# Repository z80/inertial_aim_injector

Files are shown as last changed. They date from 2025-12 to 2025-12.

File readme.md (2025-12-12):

# A hardware project - Inertial Aiming Override for DualSense Playstation 5 controller.

| Image 1 | Image 2 |
|---|---|
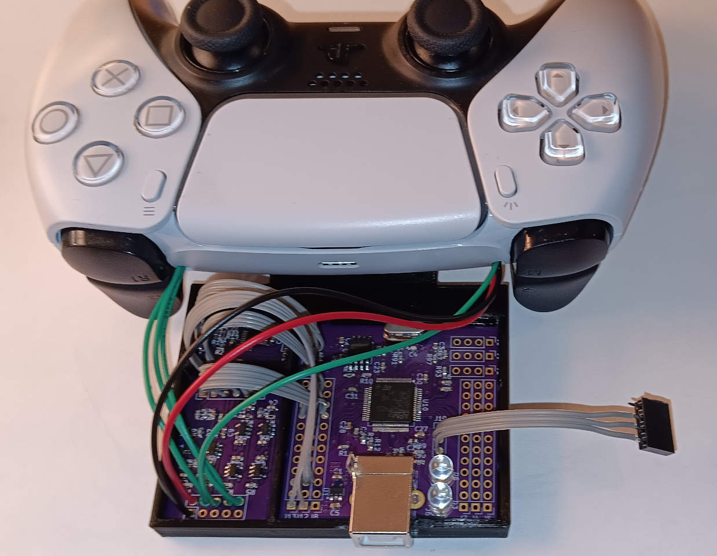
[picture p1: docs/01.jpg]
Image A
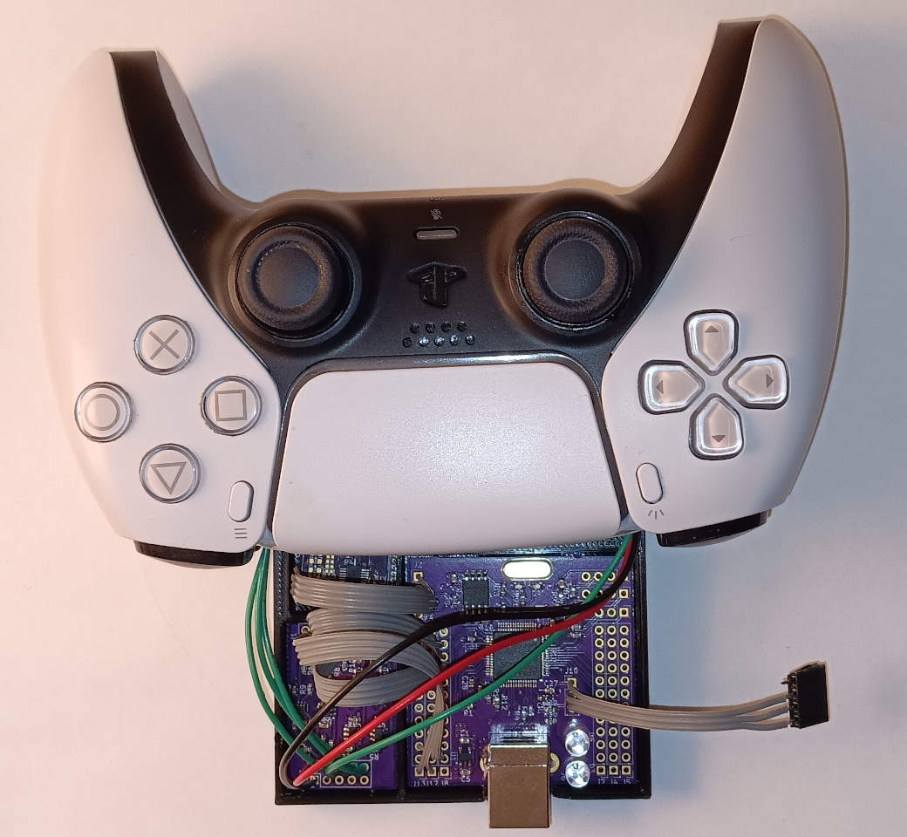
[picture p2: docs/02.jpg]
Image B
|  |  |

Constant overshooting? 
Frustrating undershooting? 
The endless struggle to place the crosshair exactly on target? 
Thumbsticks that refuse to obey your intent? Another great game launches - only for you to discover it does not support inertial aiming? 

Looks familiar?  

**Scenes like these are happening all over the galaxy right now!**

But there is a way forward. 
Forget the fight against clumsy thumbsticks. 
Embrace inertial aiming override.  

Play on par with keyboard and mouse players.  
Achieve precision where there was chaos.  
Experience smooth control where there was frustration.  
Unlock faster reaction times with natural motion input.  

Spread inertial aiming accuracy across every battlefield.  
Use the inertial aiming override device.  
Leave the thumbstick struggle behind.

This repository contains a prototype hardware/firmware project that **overrides the internal thumbstick signals of a PlayStation DualSense controller** using an external inertial sensor (BMI085 IMU).  
The goal: enable **inertial aiming** in games that do not natively support it, by forcing thumbstick input derived from gyroscope/accelerometer data.
There are a few products on the market which filter USB trafic of the controller and inject keyboard and mouse. However, it only can work as soon as it is over USB and not over Bluetooth.
The hardware override ensures that it works no matter what.

---

## Target Games

This override is intended to make aiming more convenient in titles lacking native inertial support:

| Picture | Game | Notes |
|---|---|---|
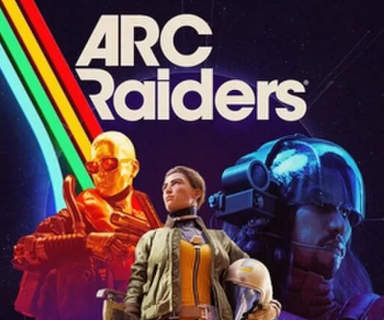
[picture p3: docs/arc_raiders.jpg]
Arc Raiders
|  | Arc Raiders | No native inertial aiming |
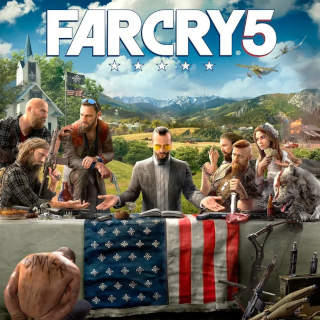
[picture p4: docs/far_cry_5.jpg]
Far Cry 5
|  | Far Cry 5 | No native inertial aiming support neither |
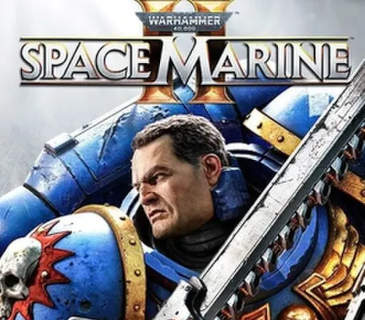
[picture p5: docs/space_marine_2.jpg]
Space Marine 2
|  |Space Marine 2 | No native inertial aiming |
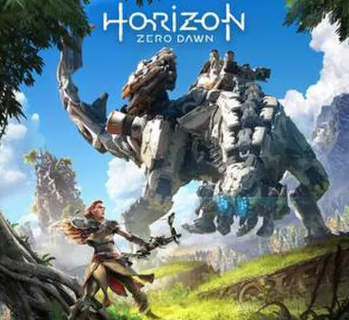
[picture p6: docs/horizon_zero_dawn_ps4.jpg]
Horizon Zero Dawn PS4
|  |Horizon Zero Dawn (PS4) | PS5 version supports inertial aiming but the main character has been made less cute |
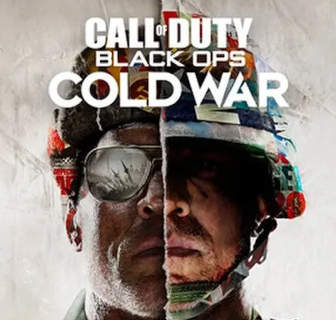
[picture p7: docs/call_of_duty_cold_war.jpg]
call of Duty: Black Ops Cold War
|  |Call of Duty: Black Ops Cold War | No native inertial aiming |
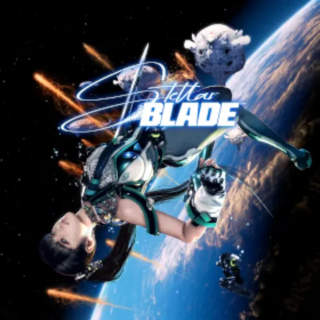
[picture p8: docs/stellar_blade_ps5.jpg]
Stellar Blade PS5
|  |Stellar Blade | No native inertial aiming, needed when shooting targets |

*(More titles may be added as I find out the intertial aiming status)*

---

## 📂 Project Structure

- **`firmware/`**  
  Board configuration for MicroPython firmware supporting the BMI085 IMU.  
  Runs on a custom STM32F405 board with USB‑B and 16 MB SPI flash.

- **`mechanical/`**  
  Blender3D project for the mechanical tray.  
  Designed to attach under the DualSense controller with double‑sided tape.

- **`python/`**  
  Contains `main.py` - the control logic.  
  Current firmware is binary (on/off), but Python makes it easy to experiment with sensitivity curves (e.g., scaling with L2 button depth).

- **`schematics/`**  
  Three PCB designs:
  - `board_bmi085` → breakout for BMI085 IMU  
  - `mp_board` → custom MicroPython‑capable STM32F405RGT6 board with USB‑B and 16MB flash  
  - `override_board` → power management + signal injection  
    - Uses TPS22948 with reverse current blocking  
    - Energizes only when the DualSense thumbsticks are active  
    - Senses L2 button position and drives voltages into the right thumbstick X/Y axes

---

## Deadzone Observations

During testing, the DualSense thumbstick showed **nonsymmetrical deadzones**:

- Neutral voltage - **0.9V**
- Both X and Y axes have insensitive intervals around neutral
- Positive and negative directions differ in width
- Deadzone ranges vary slightly between axes
- Likely **controller-specific**. Different units may have different calibration tables. I only have one to play with.

This means injected signals must account for asymmetric thresholds to achieve smooth inertial aiming.

---

## Disclaimer

This is a **prototype project - not a finished product**.  
- Built for personal experimentation and proof‑of‑concept.  
- If you want to reproduce or extend it, more copies can be made.  
- For compactness and convenience, a **single‑board override design** is recommended (instead of the current 3‑board stack).  

Use at your own risk. This project is not affiliated with Sony or PlayStation.

---

## Future Directions

- Consolidate into a single PCB for easier replication  
- Add configurable sensitivity curves (e.g., proportional to L2 depth)  
- Explore per-controller calibration routines to compensate for asymmetric deadzones  
- Community contributions welcome: firmware tweaks, mechanical refinements, or new game compatibility reports

---

## Project Status

Prototype stage. Contributions, forks, and experiments are encouraged!

---

## Get Involved

This project is still in its prototype stage, but curiosity and experimentation are what keep it alive.  
If the idea of overriding thumbstick signals with inertial aiming sparks your interest, I’d love to hear from you.  

Feel free to open an issue, share your thoughts, or suggest improvements.  
Even a simple "I’d like to try this" helps gauge whether others find value in the concept.  
Your feedback will shape whether this remains a one‑off experiment or grows into something more refined.

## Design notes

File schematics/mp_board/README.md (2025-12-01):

A custom MicroPython-based Stm32 board with integrated Flash memory.

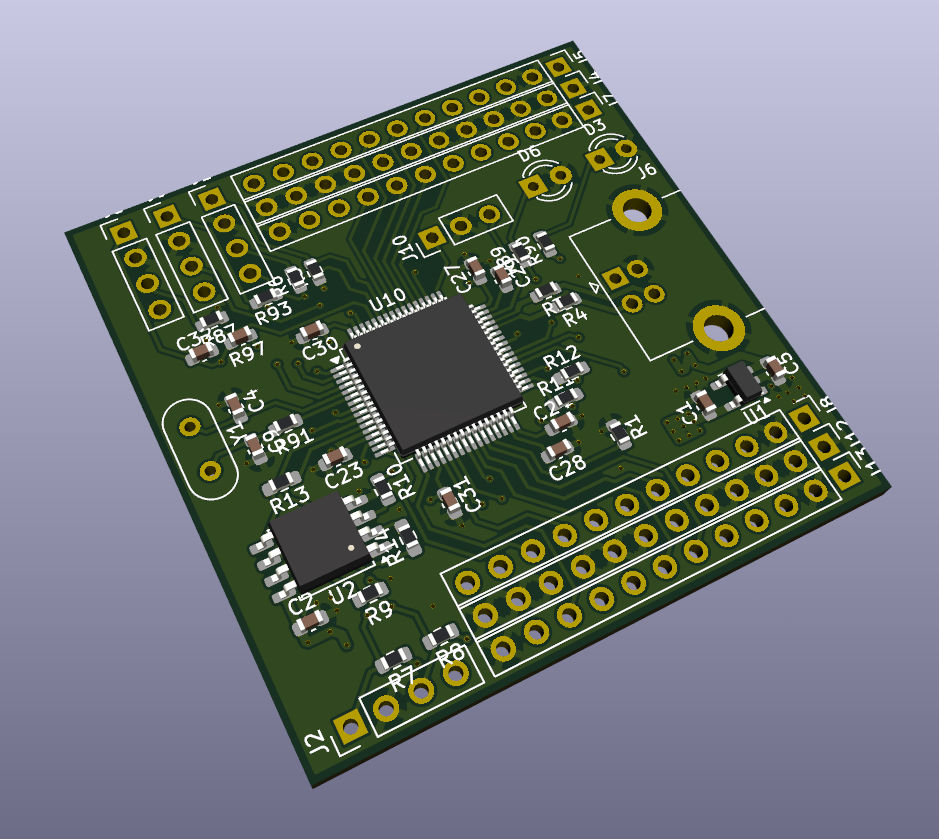
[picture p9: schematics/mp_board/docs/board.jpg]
board


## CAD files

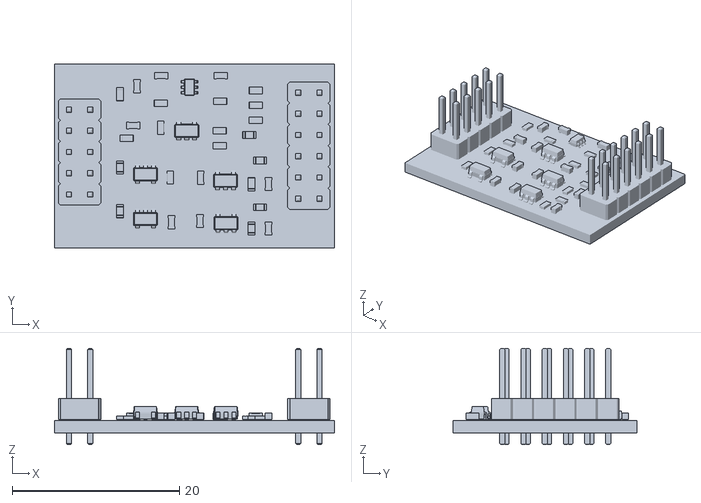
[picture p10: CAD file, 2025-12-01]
schematics/override_board/override_board/3d/override_board.stl
33.5 x 22.0 x 11.5

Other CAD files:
mechanical/override_pcbs_holder.blend

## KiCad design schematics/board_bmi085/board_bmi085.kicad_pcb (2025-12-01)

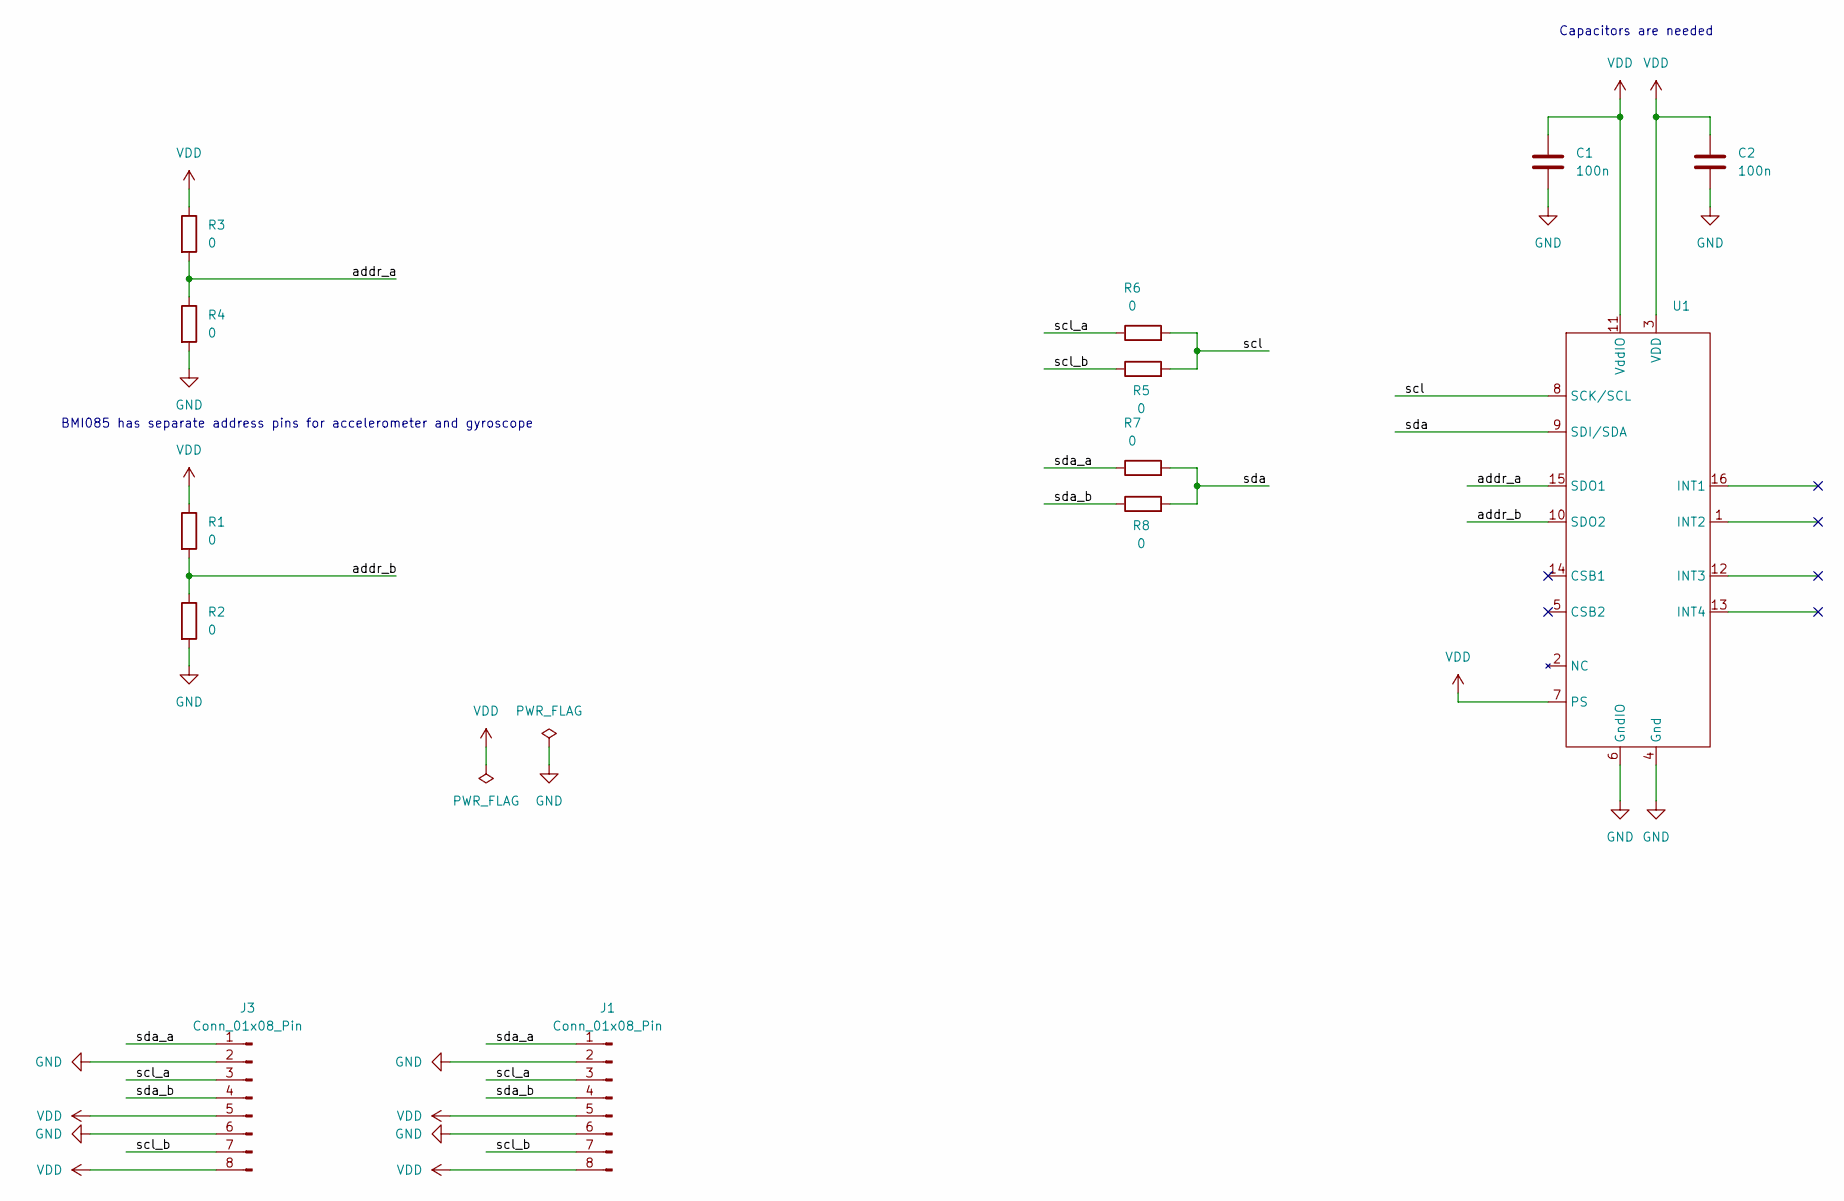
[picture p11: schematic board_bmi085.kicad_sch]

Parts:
C1, C2: 100n; C_0603_1608Metric
J1, J3: Conn_01x08_Pin; PinHeader_1x08_P1.27mm_Vertical
R1, R2, R3, R4, R5, R6, R7, R8: 0; R_0402_1005Metric
U1: BMI085

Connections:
/addr_a: R3.2, R4.1, U1.15 (SDO1)
/addr_b: R1.2, R2.1, U1.10 (SDO2)
/scl: R5.2, R6.2, U1.8 (SCK/SCL)
/scl_a: J1.3, J3.3, R6.1
/scl_b: J1.7, J3.7, R5.1
/sda: R7.2, R8.2, U1.9 (SDI/SDA)
/sda_a: J1.1, J3.1, R7.1
/sda_b: J1.4, J3.4, R8.1
GND: C1.2, C2.2, J1.2, J1.6, J3.2, J3.6, R2.2, R4.2, U1.4 (Gnd), U1.6 (GndIO)
VDD: C1.1, C2.1, J1.5, J1.8, J3.5, J3.8, R1.1, R3.1, U1.3 (VDD), U1.7 (PS), U1.11 (VddIO)

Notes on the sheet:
Capacitors are needed
BMI085 has separate address pins for accelerometer and gyroscope

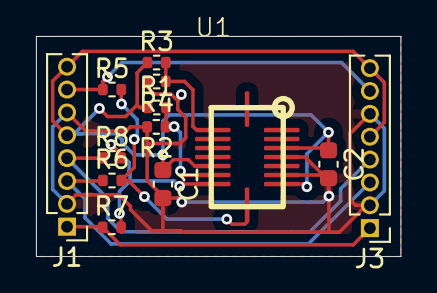
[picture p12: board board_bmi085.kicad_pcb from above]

Board: 2 copper layers, 20.2 x 12.2 mm, 13 parts (0 on the bottom side), 10 nets.

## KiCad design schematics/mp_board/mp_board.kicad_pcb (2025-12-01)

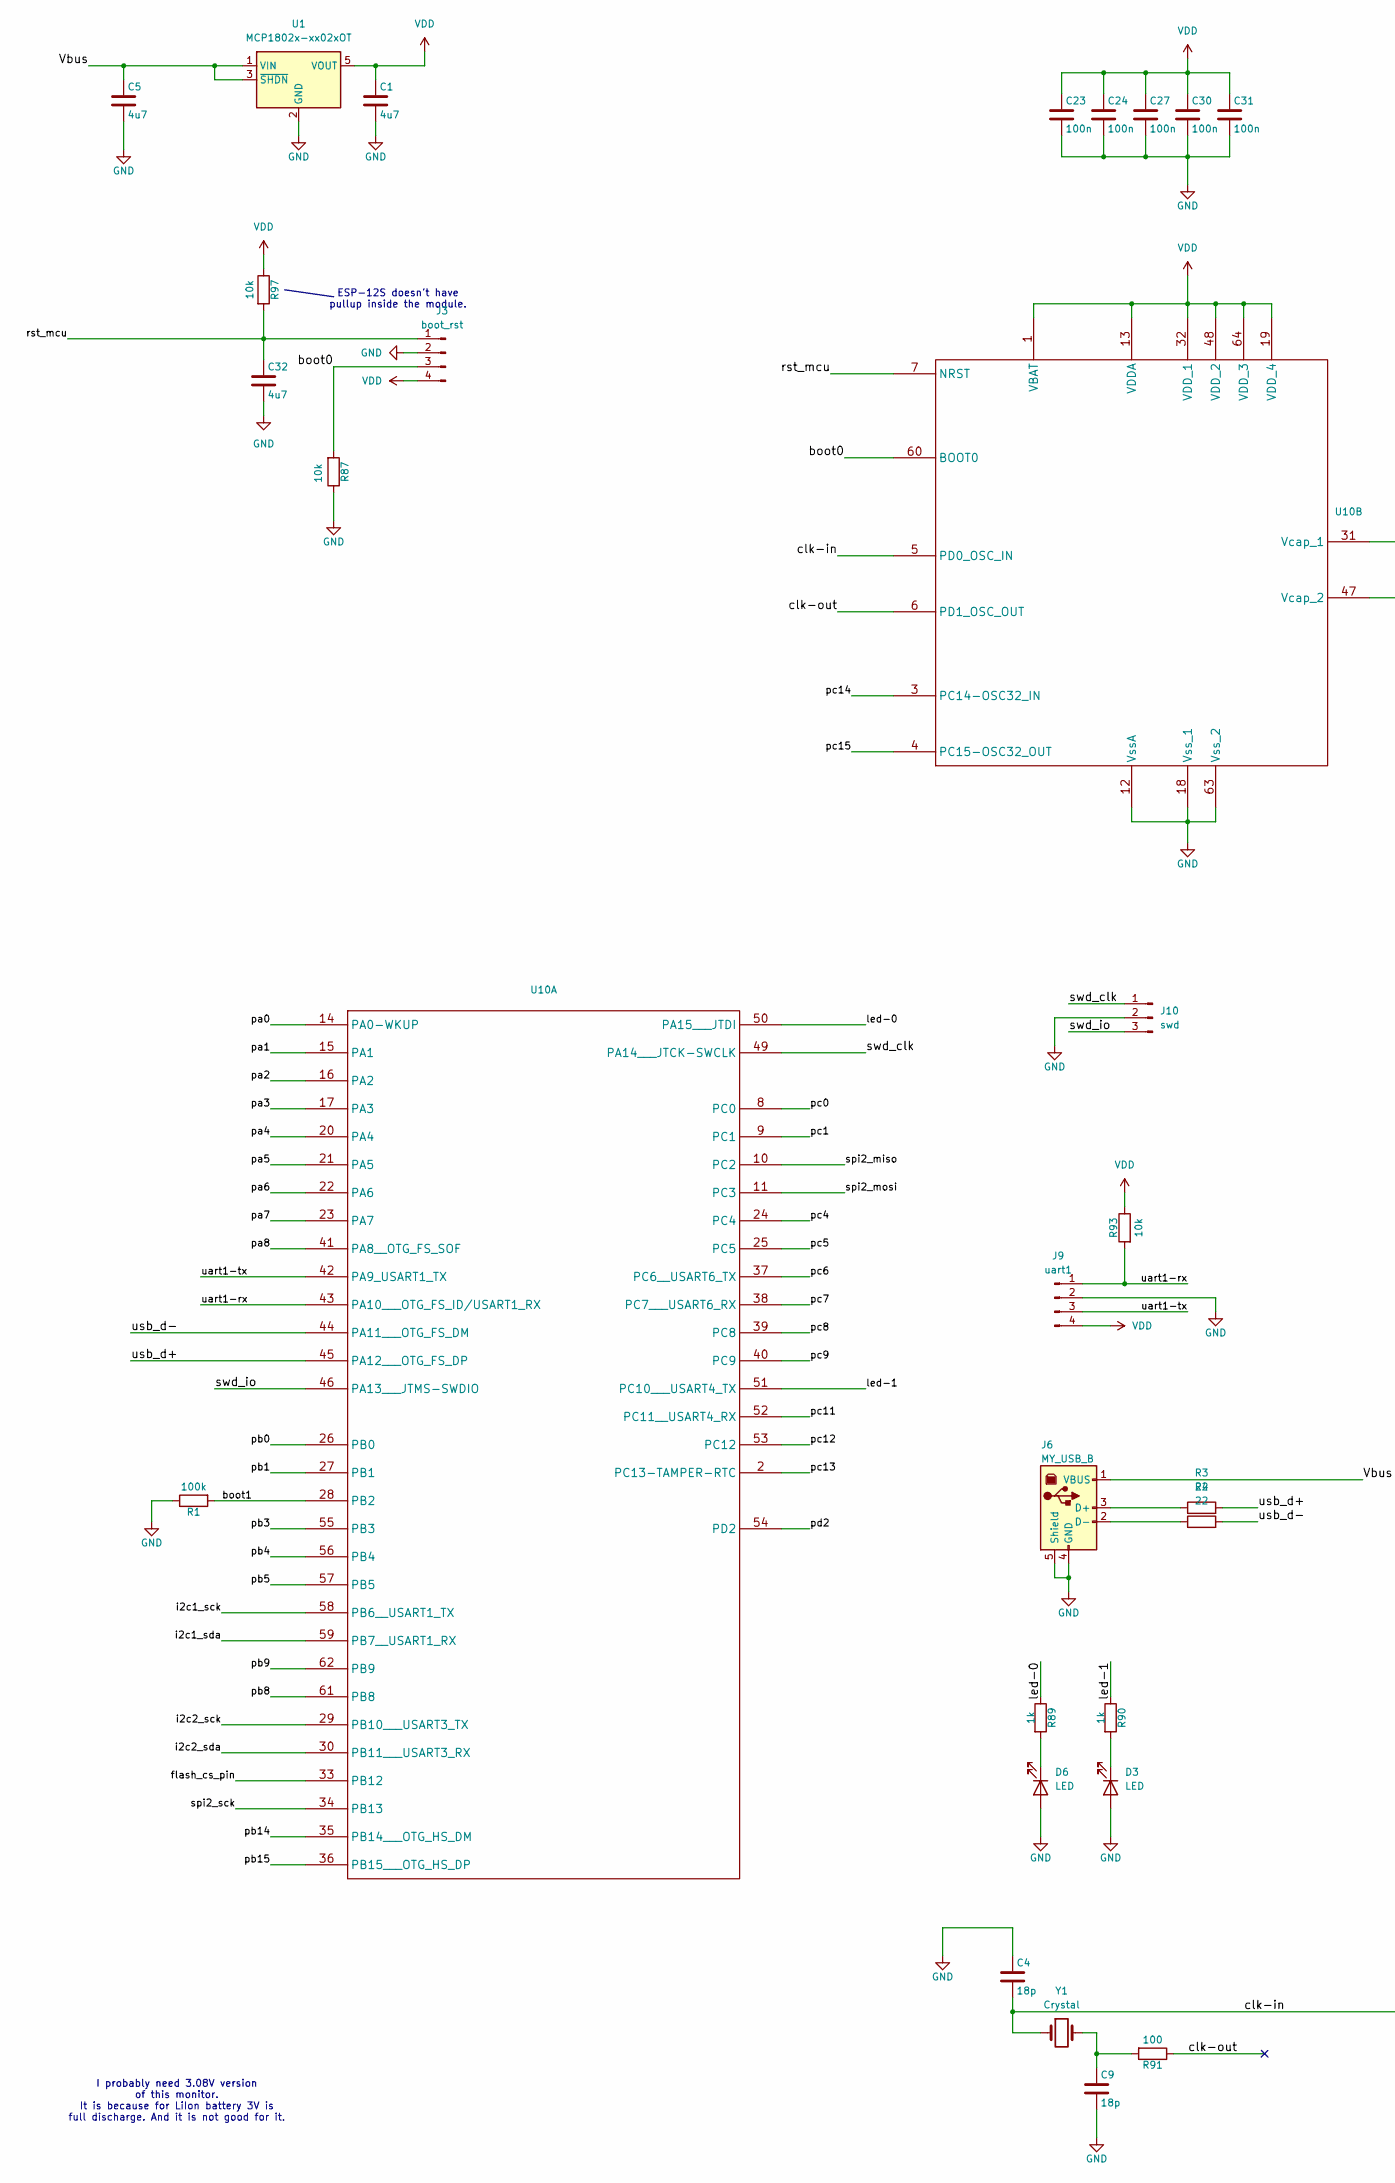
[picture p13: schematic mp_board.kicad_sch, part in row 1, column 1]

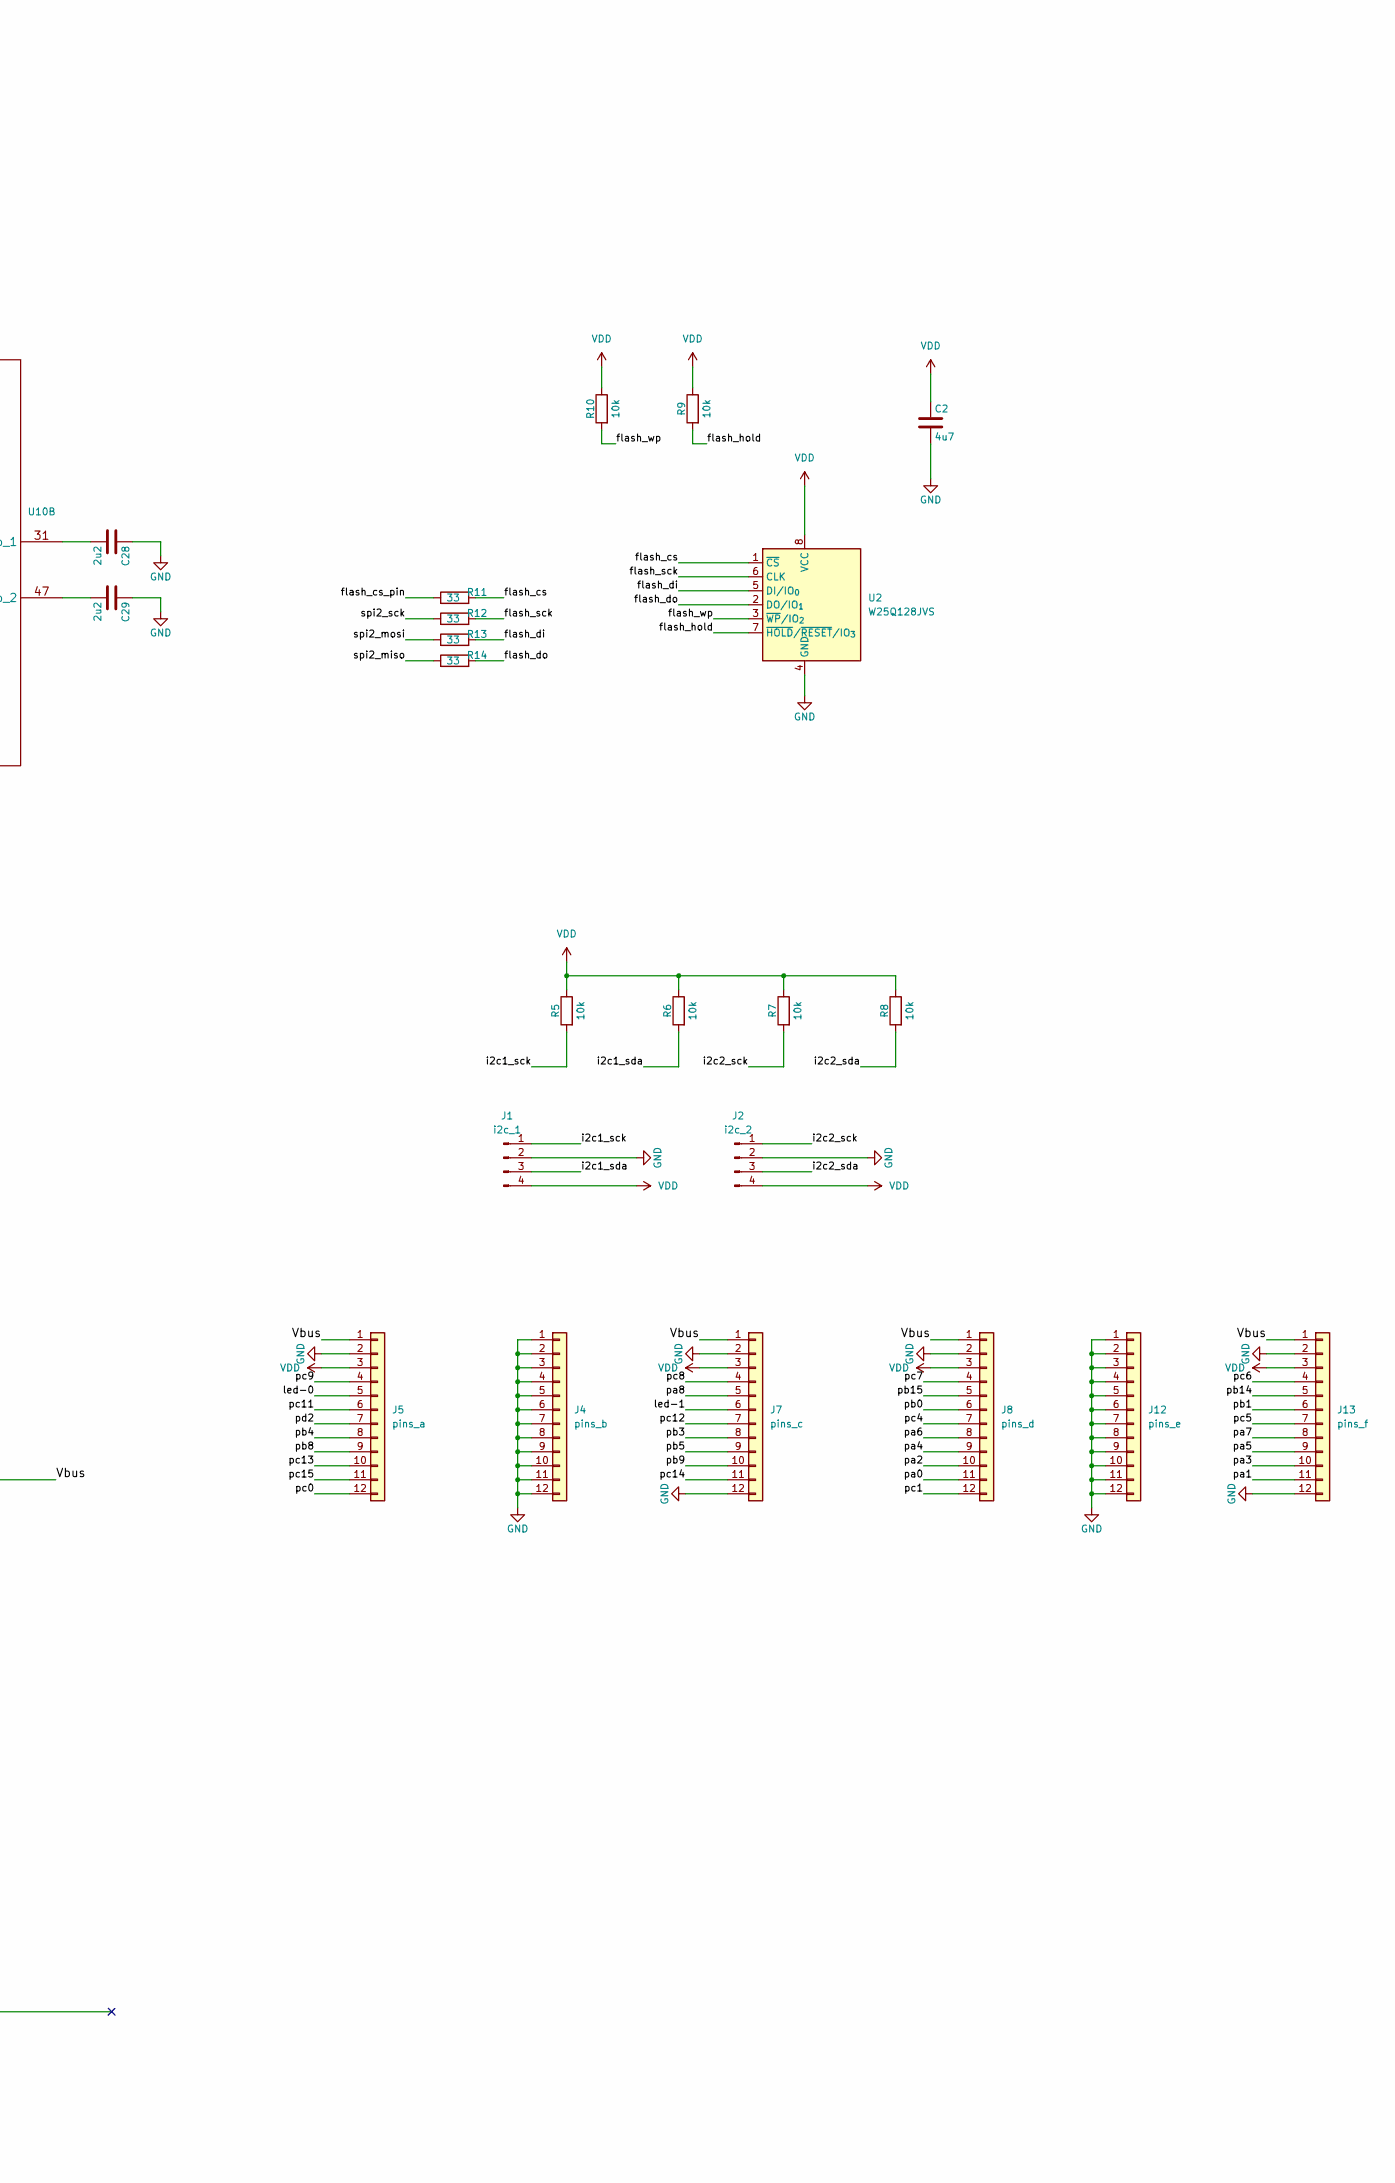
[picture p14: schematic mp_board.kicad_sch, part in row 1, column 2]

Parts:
C1, C2, C5, C32: 4u7; C_0603_1608Metric
C4, C9: 18p; C_0603_1608Metric
C23, C24, C27, C30, C31: 100n; C_0603_1608Metric
C28, C29: 2u2; C_0603_1608Metric
D3, D6: LED; LED_D3.0mm
J1: i2c_1; PinHeader_1x04_P2.54mm_Vertical
J2: i2c_2; PinHeader_1x04_P2.54mm_Vertical
J3: boot_rst; PinHeader_1x04_P2.54mm_Vertical
J4: pins_b; PinHeader_1x12_P2.54mm_Vertical
J5: pins_a; PinHeader_1x12_P2.54mm_Vertical
J6: MY_USB_B; USB_B_Lumberg_2411_02_Horizontal
J7: pins_c; PinHeader_1x12_P2.54mm_Vertical
J8: pins_d; PinHeader_1x12_P2.54mm_Vertical
J9: uart1; PinHeader_1x04_P2.54mm_Vertical
J10: swd; PinHeader_1x03_P2.54mm_Vertical
J12: pins_e; PinHeader_1x12_P2.54mm_Vertical
J13: pins_f; PinHeader_1x12_P2.54mm_Vertical
R1: 100k; R_0603_1608Metric
R3, R4: 22; R_0603_1608Metric
R5, R6, R7, R8, R9, R10, R87, R93: 10k; R_0603_1608Metric
R11, R12, R13, R14: 33; R_0603_1608Metric_Pad0.98x0.95mm_HandSolder
R89, R90: 1k; R_0603_1608Metric
R91: 100; R_0603_1608Metric
R97: 10k; C_0603_1608Metric
U1: MCP1802x-xx02xOT; SOT-23-5
U2: W25Q128JVS; SOIC-8_5.3x5.3mm_P1.27mm
U10: LQFP-64_10x10mm_P0.5mm
Y1: Crystal; Crystal_HC52-8mm_Vertical

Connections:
/Vbus: C5.1, J5.1, J6.1 (VBUS), J7.1, J8.1, J13.1, U1.1 (VIN), U1.3 (~SHDN)
/boot0: J3.3, R87.2, U10.60 (BOOT0)
/boot1: R1.2, U10.28 (PB2)
/clk-in: C4.2, U10.5 (PD0_OSC_IN), Y1.1
/clk-out: R91.1, U10.6 (PD1_OSC_OUT)
/flash_cs: R11.2, U2.1 (~CS)
/flash_cs_pin: R11.1, U10.33 (PB12)
/flash_di: R13.2, U2.5 (DI/IO_{0})
/flash_do: R14.2, U2.2 (DO/IO_{1})
/flash_hold: R9.2, U2.7 (~HOLD/~RESET/IO_{3})
/flash_sck: R12.2, U2.6 (CLK)
/flash_wp: R10.2, U2.3 (~WP/IO_{2})
/i2c1_sck: J1.1, R5.2, U10.58 (PB6__USART1_TX)
/i2c1_sda: J1.3, R6.2, U10.59 (PB7__USART1_RX)
/i2c2_sck: J2.1, R7.2, U10.29 (PB10___USART3_TX)
/i2c2_sda: J2.3, R8.2, U10.30 (PB11___USART3_RX)
/led-0: J5.5, R89.1, U10.50 (PA15___JTDI)
/led-1: J7.6, R90.1, U10.51 (PC10___USART4_TX)
/pa0: J8.11, U10.14 (PA0-WKUP)
/pa1: J13.11, U10.15 (PA1)
/pa2: J8.10, U10.16 (PA2)
/pa3: J13.10, U10.17 (PA3)
/pa4: J8.9, U10.20 (PA4)
/pa5: J13.9, U10.21 (PA5)
/pa6: J8.8, U10.22 (PA6)
/pa7: J13.8, U10.23 (PA7)
/pa8: J7.5, U10.41 (PA8__OTG_FS_SOF)
/pb0: J8.6, U10.26 (PB0)
/pb1: J13.6, U10.27 (PB1)
/pb3: J7.8, U10.55 (PB3)
/pb4: J5.8, U10.56 (PB4)
/pb5: J7.9, U10.57 (PB5)
/pb8: J5.9, U10.61 (PB8)
/pb9: J7.10, U10.62 (PB9)
/pb14: J13.5, U10.35 (PB14___OTG_HS_DM)
/pb15: J8.5, U10.36 (PB15___OTG_HS_DP)
/pc0: J5.12, U10.8 (PC0)
/pc1: J8.12, U10.9 (PC1)
/pc4: J8.7, U10.24 (PC4)
/pc5: J13.7, U10.25 (PC5)
/pc6: J13.4, U10.37 (PC6__USART6_TX)
/pc7: J8.4, U10.38 (PC7___USART6_RX)
/pc8: J7.4, U10.39 (PC8)
/pc9: J5.4, U10.40 (PC9)
/pc11: J5.6, U10.52 (PC11__USART4_RX)
/pc12: J7.7, U10.53 (PC12)
/pc13: J5.10, U10.2 (PC13-TAMPER-RTC)
/pc14: J7.11, U10.3 (PC14-OSC32_IN)
/pc15: J5.11, U10.4 (PC15-OSC32_OUT)
/pd2: J5.7, U10.54 (PD2)
/rst_mcu: C32.1, J3.1, R97.2, U10.7 (NRST)
/spi2_miso: R14.1, U10.10 (PC2)
/spi2_mosi: R13.1, U10.11 (PC3)
/spi2_sck: R12.1, U10.34 (PB13)
/swd_clk: J10.1, U10.49 (PA14___JTCK-SWCLK)
/swd_io: J10.3, U10.46 (PA13___JTMS-SWDIO)
/uart1-rx: J9.1, R93.2, U10.43 (PA10___OTG_FS_ID/USART1_RX)
/uart1-tx: J9.3, U10.42 (PA9_USART1_TX)
/usb_d+: R3.2, U10.45 (PA12___OTG_FS_DP)
/usb_d-: R4.2, U10.44 (PA11___OTG_FS_DM)
GND: C1.2, C2.2, C4.1, C5.2, C9.2, C23.2, C24.2, C27.2, C28.1, C29.1, C30.2, C31.2, C32.2, D3.2 (A), D6.2 (A), J1.2, J2.2, J3.2, J4.1, J4.2, J4.3, J4.4, J4.5, J4.6, J4.7, J4.8, J4.9, J4.10, J4.11, J4.12, J5.2, J6.4 (GND), J6.5 (Shield), J7.2, J7.12, J8.2, J9.2, J10.2, J12.1, J12.2, J12.3, J12.4, J12.5, J12.6, J12.7, J12.8, J12.9, J12.10, J12.11, J12.12, J13.2, J13.12, R1.1, R87.1, U1.2 (GND), U2.4 (GND), U10.12 (VssA), U10.18 (Vss_1), U10.63 (Vss_2)
unnamed: C9.1, R91.2, Y1.2
unnamed: D3.1 (K), R90.2
unnamed: D6.1 (K), R89.2
unnamed: J6.3 (D+), R3.1
unnamed: J6.2 (D-), R4.1
unnamed: C28.2, U10.31 (Vcap_1)
unnamed: C29.2, U10.47 (Vcap_2)
VDD: C1.1, C2.1, C23.1, C24.1, C27.1, C30.1, C31.1, J1.4, J2.4, J3.4, J5.3, J7.3, J8.3, J9.4, J13.3, R5.1, R6.1, R7.1, R8.1, R9.1, R10.1, R93.1, R97.1, U1.5 (VOUT), U2.8 (VCC), U10.1 (VBAT), U10.13 (VDDA), U10.19 (VDD_4), U10.32 (VDD_1), U10.48 (VDD_2), U10.64 (VDD_3)

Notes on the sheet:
I probably need 3.08V version of this monitor. It is because for LiIon battery 3V is full discharge. And it is not good for it.
ESP-12S doesn't have pullup inside the module.

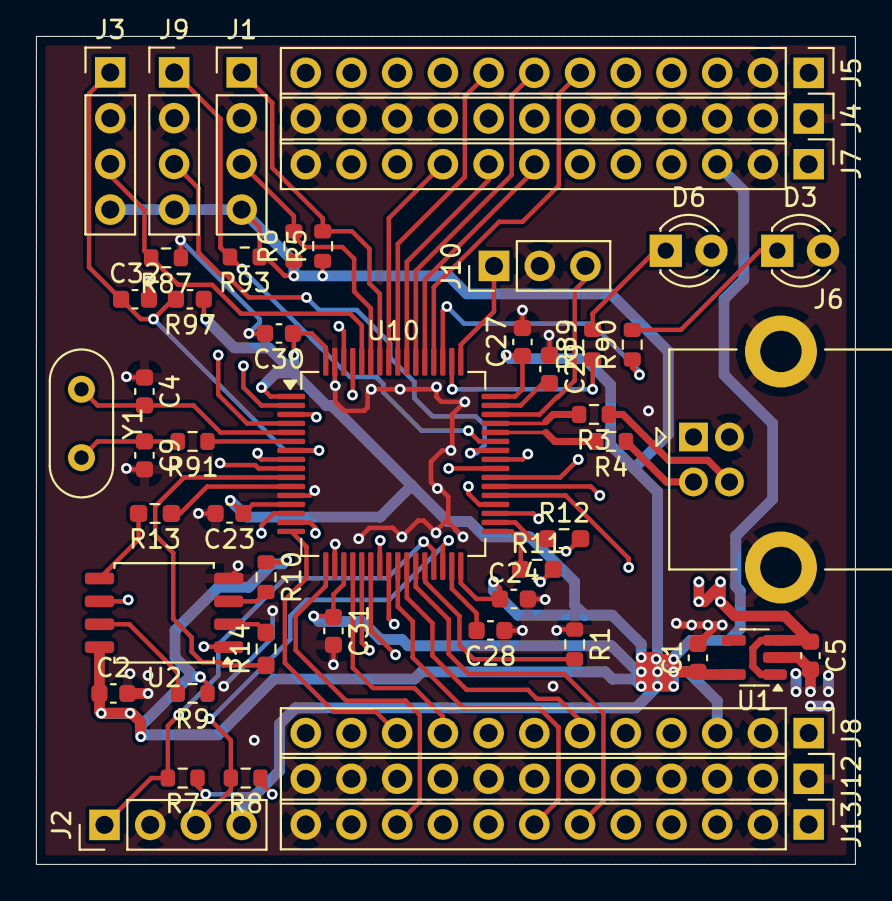
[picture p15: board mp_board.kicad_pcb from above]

Board: 4 copper layers, 45.5 x 46.0 mm, 50 parts (0 on the bottom side), 69 nets.

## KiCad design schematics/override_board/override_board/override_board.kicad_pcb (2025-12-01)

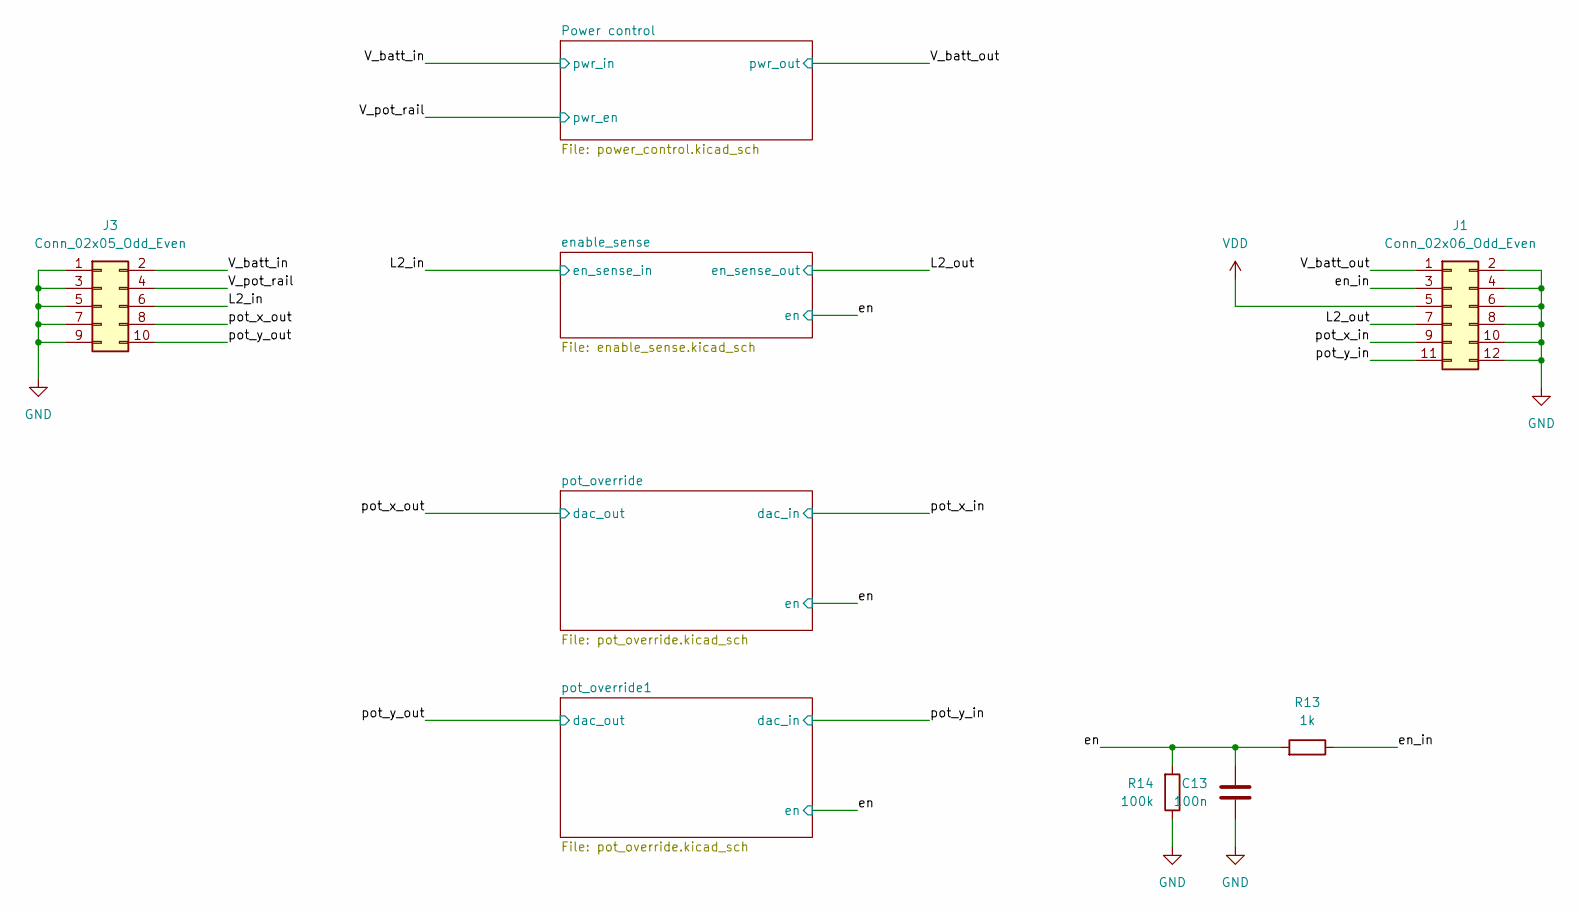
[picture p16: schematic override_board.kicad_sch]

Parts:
C13: 100n; C_0603_1608Metric
J1: Conn_02x06_Odd_Even; PinHeader_2x06_P2.54mm_Vertical
J3: Conn_02x05_Odd_Even; PinHeader_2x05_P2.54mm_Vertical
R13: 1k; R_0603_1608Metric
R14: 100k; R_0603_1608Metric

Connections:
/L2_in: J3.6; also elsewhere on the board
/L2_out: J1.7; also elsewhere on the board
/V_batt_in: J3.2; also elsewhere on the board
/V_batt_out: J1.1; also elsewhere on the board
/V_pot_rail: J3.4; also elsewhere on the board
/en: C13.1, R13.2, R14.2; also elsewhere on the board
/en_in: J1.3, R13.1
/pot_x_in: J1.9; also elsewhere on the board
/pot_x_out: J3.8; also elsewhere on the board
/pot_y_in: J1.11; also elsewhere on the board
/pot_y_out: J3.10; also elsewhere on the board
GND: C13.2, J1.2, J1.4, J1.6, J1.8, J1.10, J1.12, J3.1, J3.3, J3.5, J3.7, J3.9, R14.1; also elsewhere on the board
VDD: J1.5; also elsewhere on the board

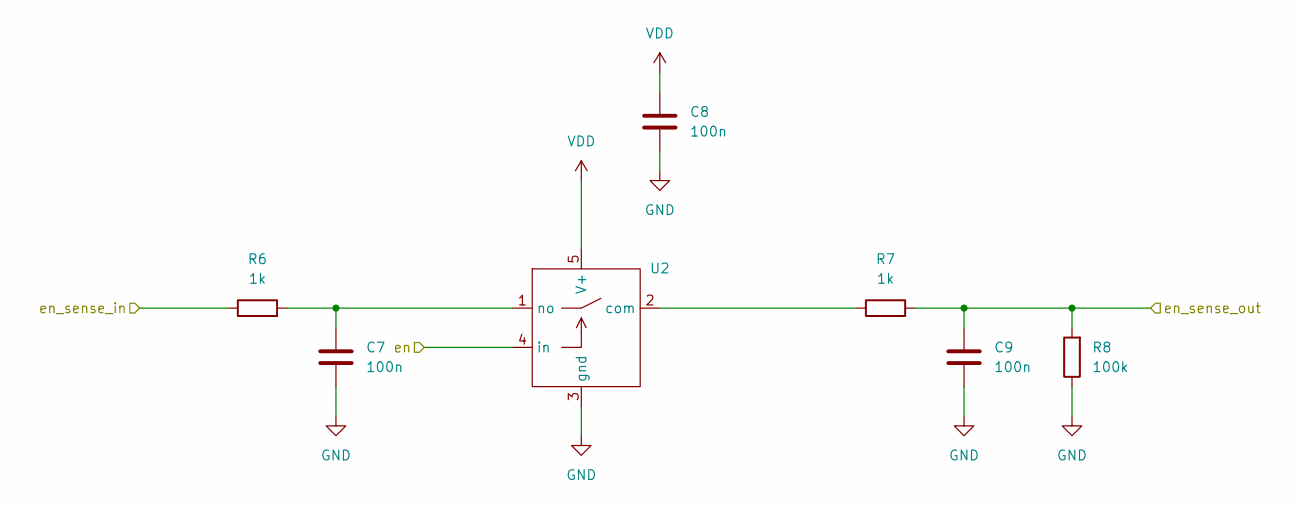
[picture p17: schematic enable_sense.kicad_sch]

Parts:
C7, C8, C9: 100n; C_0603_1608Metric
R6, R7: 1k; R_0603_1608Metric
R8: 100k; R_0603_1608Metric
U2: SOT-23-5

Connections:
/L2_in: R6.1; also elsewhere on the board
/L2_out: C9.1, R7.2, R8.2; also elsewhere on the board
/en: U2.4 (in); also elsewhere on the board
GND: C7.2, C8.2, C9.2, R8.1, U2.3 (gnd); also elsewhere on the board
unnamed: R7.1, U2.2 (com)
unnamed: C7.1, R6.2, U2.1 (no)
VDD: C8.1, U2.5 (V+); also elsewhere on the board

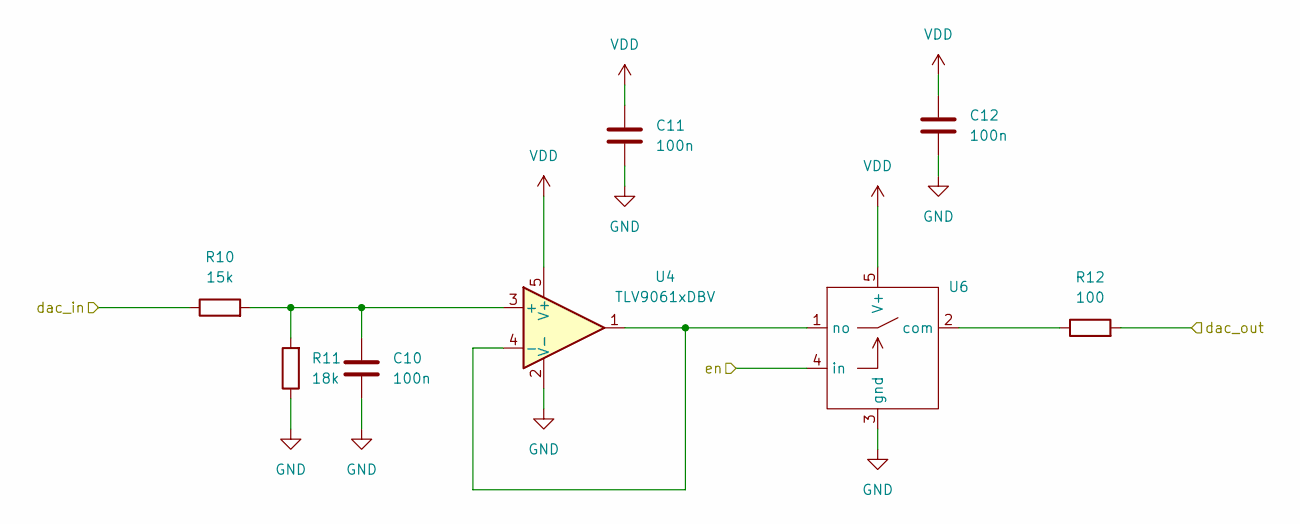
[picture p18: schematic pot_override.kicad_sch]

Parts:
C10, C11, C12: 100n; C_0603_1608Metric
R10: 15k; R_0603_1608Metric
R11: 18k; R_0603_1608Metric
R12: 100; R_0603_1608Metric
U4: TLV9061xDBV; SOT-23-5
U6: SOT-23-5

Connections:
/en: U6.4 (in); also elsewhere on the board
/pot_x_in: R10.1; also elsewhere on the board
/pot_x_out: R12.2; also elsewhere on the board
GND: C10.2, C11.2, C12.2, R11.1, U4.2 (V-), U6.3 (gnd); also elsewhere on the board
unnamed: C10.1, R10.2, R11.2, U4.3 (+)
unnamed: U4.1, U4.4 (-), U6.1 (no)
unnamed: R12.1, U6.2 (com)
VDD: C11.1, C12.1, U4.5 (V+), U6.5 (V+); also elsewhere on the board

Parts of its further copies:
C4, C5, C6: 100n; C_0603_1608Metric
R3: 15k; R_0603_1608Metric
R4: 18k; R_0603_1608Metric
R5: 100; R_0603_1608Metric
U3: TLV9061xDBV; SOT-23-5
U5: SOT-23-5

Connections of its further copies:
/en: U5.4 (in); also elsewhere on the board
/pot_y_in: R3.1; also elsewhere on the board
/pot_y_out: R5.2; also elsewhere on the board
GND: C4.2, C5.2, C6.2, R4.1, U3.2 (V-), U5.3 (gnd); also elsewhere on the board
unnamed: C4.1, R3.2, R4.2, U3.3 (+)
unnamed: U3.1, U3.4 (-), U5.1 (no)
unnamed: R5.1, U5.2 (com)
VDD: C5.1, C6.1, U3.5 (V+), U5.5 (V+); also elsewhere on the board

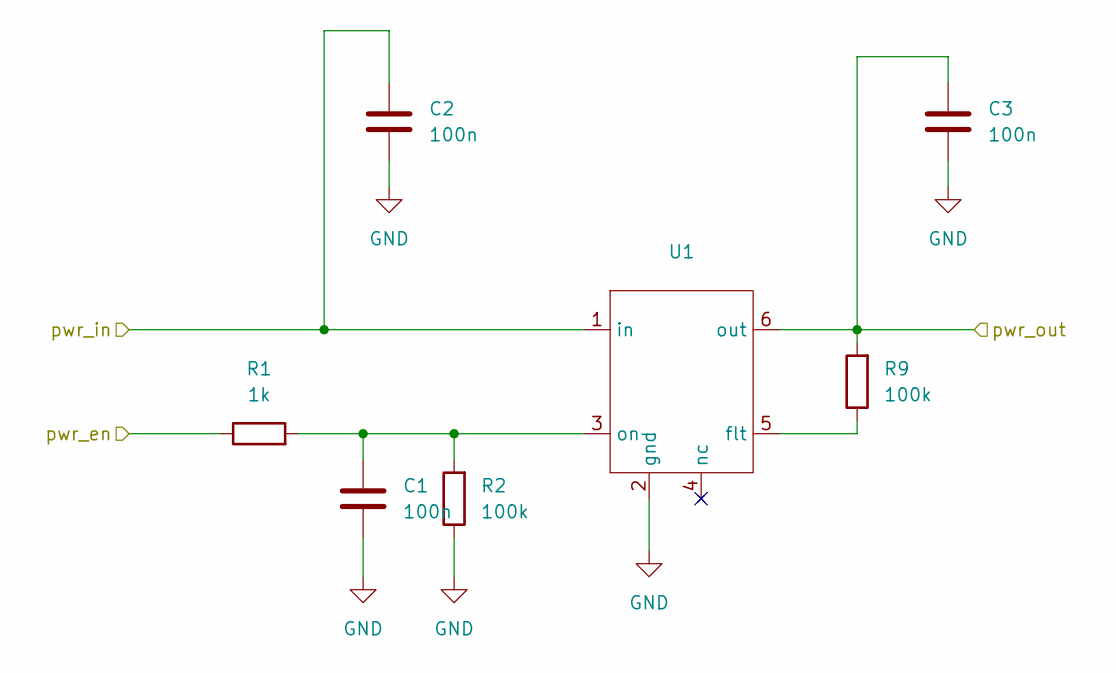
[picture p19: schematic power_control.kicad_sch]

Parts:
C1, C2, C3: 100n; C_0603_1608Metric
R1: 1k; R_0603_1608Metric
R2, R9: 100k; R_0603_1608Metric
U1: SOT-363_SC-70-6

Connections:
/V_batt_in: C2.1, U1.1 (in); also elsewhere on the board
/V_batt_out: C3.1, R9.2, U1.6 (out); also elsewhere on the board
/V_pot_rail: R1.1; also elsewhere on the board
GND: C1.2, C2.2, C3.2, R2.1, U1.2 (gnd); also elsewhere on the board
unnamed: R9.1, U1.5 (flt)
unnamed: C1.1, R1.2, R2.2, U1.3 (on)

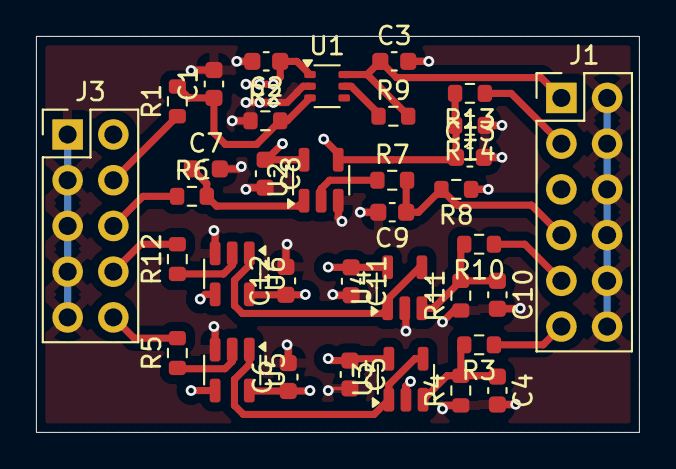
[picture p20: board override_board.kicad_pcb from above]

Board: 4 copper layers, 33.5 x 22.0 mm, 35 parts (0 on the bottom side), 23 nets.

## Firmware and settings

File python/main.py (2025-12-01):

import time
from machine import I2C, Pin
from pyb import Pin, DAC, ADC
import bmi08
GAIN_X = 1.0
GAIN_Y = 1.0
GAIN_Z = -1.0

OUT_EN_TH = 750
OUT_DIS_TH = 800
out_en = False

DAC_ZERO = 2048 + 700
DAC_RANGE = 1340

GYRO_X_DEAD_ZONE = 5
GYRO_Y_DEAD_ZONE = 5
GYRO_Z_DEAD_ZONE = 5

# Vertical
DAC_X_DEAD_ZONE_P = 600 # Down
DAC_X_DEAD_ZONE_N = 550 # Up

# Not used
DAC_Y_DEAD_ZONE_P = 600
DAC_Y_DEAD_ZONE_N = 300

# Horizontal
DAC_Z_DEAD_ZONE_P = 700 # Left
DAC_Z_DEAD_ZONE_N = 500 # Right

print( "Entered" )
# Configure I2C2 with PB10 (SCL) and PB11 (SDA) at 10 kHz
i2c = I2C(2, freq=100000)
print( "Initialized I2C_2" )

dev_list = i2c.scan()
print( "dev list: ", dev_list )

imu = bmi08.BMI08(i2c)
print( "Created and configured BMI085" )

imu.init()
print( "Initialized" )

imu.init_gyro_fifo()
print( "Initialized FIFO" )

led1 = pyb.Pin('A15', Pin.OUT)
led2 = pyb.Pin('C10', Pin.OUT)

dac_x = DAC(Pin('A5'), bits=12)
dac_y = DAC(Pin('A4'), bits=12)

adc_en = ADC( Pin('A2') )
pin_en = Pin('A3', Pin.OUT)
adc_alpha = 0.3
adc_accum = 600.0

led1.off()
led2.off()
pin_en.off()

print_timeout = 25
print_counter = 0

while True:

    led1.on()
    adc = adc_en.read()
    adc_accum = adc_alpha*adc + (1.0-adc_alpha)*adc_accum
    if out_en:
        should_disable = adc_accum > OUT_DIS_TH
        if should_disable:
            out_en = False
            pin_en.off()

    else:
        should_enable = adc_accum < OUT_EN_TH
        if should_enable:
            out_en = True
            pin_en.on()

    try:
        x, y, z, qty = imu.read_gyro_sum()
    except:
        time.sleep( 0.002 )
        continue

    if qty != 0:
        led2.on()
        # 250 deg per second correspond to 32767.
        # For dac it should be 2047
        # So, max to max gain is 2047 / 32767
        scale = 2047 / (32767 * qty)
        x *= scale
        y *= scale
        z *= scale
        val_x = int(GAIN_X * x)
        if val_x > GYRO_X_DEAD_ZONE:
            val_x += DAC_X_DEAD_ZONE_P
        elif val_x < -GYRO_X_DEAD_ZONE:
            val_x -= DAC_X_DEAD_ZONE_N
        if val_x > DAC_RANGE:
            val_x = DAC_RANGE
        elif val_x < -DAC_RANGE:
            val_x = -DAC_RANGE

        val_y = int(GAIN_Y * y)
        if val_y > GYRO_Y_DEAD_ZONE:
            val_y += DAC_Y_DEAD_ZONE_P
        elif val_y < -GYRO_Y_DEAD_ZONE:
            val_y -= DAC_Y_DEAD_ZONE_N
        if val_y > DAC_RANGE:
            val_y = DAC_RANGE
        elif val_y < -DAC_RANGE:
            val_y = -DAC_RANGE

        val_z = int(GAIN_Z * z)
        if val_z > GYRO_Z_DEAD_ZONE:
            val_z += DAC_Z_DEAD_ZONE_P
        elif val_z < -GYRO_Z_DEAD_ZONE:
            val_z -= DAC_Z_DEAD_ZONE_N
        if val_z > DAC_RANGE:
            val_z = DAC_RANGE
        elif val_z < -DAC_RANGE:
            val_z = -DAC_RANGE

        out_x = val_x + DAC_ZERO
        out_y = val_y + DAC_ZERO
        out_z = val_z + DAC_ZERO

        dac_x.write( out_z )
        dac_y.write( out_x )
        led2.off()

    led1.off()

    time.sleep( 0.002 )

    print_counter += 1
    if print_counter >= print_timeout:
        #print( "x: ", val_x, "y: ", val_y, "z: ", val_z, "L2: ", adc_accum, "en: ", out_en )
        #print( "x: ", val_x, "z: ", val_z, "L2: ", adc_accum, "en: ", out_en )
        print_counter = 0
